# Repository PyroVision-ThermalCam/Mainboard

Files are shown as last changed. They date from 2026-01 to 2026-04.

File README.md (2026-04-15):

# PyroVision - Mainboard





## Table of Contents

- [PyroVision - Mainboard](#pyrovision---mainboard)
  - [Table of Contents](#table-of-contents)
  - [About](#about)
  - [License](#license)
  - [Maintainer](#maintainer)

## About

Mainboard for the PyroVision Open-Source Thermal Camera.

## License

This project is licensed under the GNU General Public License v3.0. See the [LICENSE](LICENSE) file for details.

## Maintainer

- [Daniel Kampert](mailto:daniel.kampert@kampis-elektroecke.de)

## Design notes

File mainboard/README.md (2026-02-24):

<p align="center" width="100%">
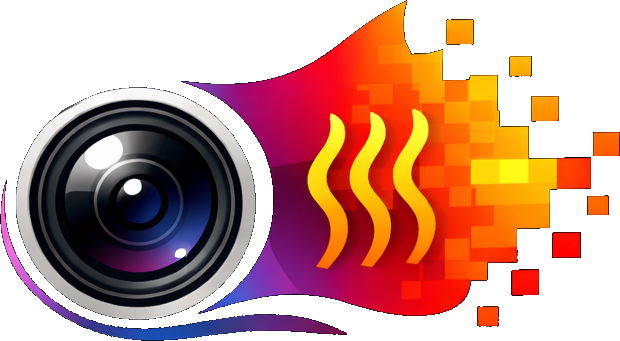
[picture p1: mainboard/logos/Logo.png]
  
</p>

<h1 align="center">PyroVision Mainboard</h1>

<p align="center" width="100%">
  <a href="${GIT_URL}/actions/workflows/pcb.yaml">
    CI Badge
  </a>
</p>

***

<p align="center">
  3D Top Angled
&nbsp; &nbsp; &nbsp; &nbsp;
  3D Bottom Angled
</p>

***

## SPECIFICATIONS

| Parameter | Value |
| --- | --- |
| Dimensions | 32.0 × 24.0 mm |

***

## DIRECTORY STRUCTURE

    .
    ├─ Computations       # Misc calculations
    ├─ HTML               # HTML files for generated webpage
    ├─ Images             # Pictures and renders
    │
    ├─ kibot_resources    # External resources for KiBot
    │  ├─ colors          # Color theme for KiCad
    │  ├─ fonts           # Fonts used in the project
    │  ├─ scripts         # External scripts used with KiBot
    │  └─ templates       # Templates for KiBot generated reports
    │
    ├─ kibot_yaml         # KiBot YAML config files
    ├─ KiRI               # KiRI (PCB diff viewer) files
    │
    ├─ lib                # KiCad footprint and symbol libraries
    │  ├─ 3d_models       # Component 3D models
    │  ├─ lib_fp          # Footprint libraries
    │  └─ lib_sym         # Symbol libraries
    │
    ├─ logos              # Logos
    │
    ├─ Manufacturing      # Assembly and fabrication documents
    │  ├─ Assembly        # Assembly documents (BoM, pos, notes)
    │  │
    │  └─ Fabrication     # Fabrication documents (ZIP, notes)
    │     ├─ Drill Tables # CSV drill tables
    │     └─ Gerbers      # Gerbers
    │
    ├─ Report             # Reports for ERC/DRC
    ├─ Schematic          # PDF of schematic
    ├─ templates          # Title block templates
    ├─ Testing
    │  └─ Testpoints      # Testpoints tables
    │
    └─ Variants           # Outputs for assembly variants

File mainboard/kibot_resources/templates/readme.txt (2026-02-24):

<p align="center" width="100%">
  
</p>

<h1 align="center">${BOARD_NAME}</h1>

<p align="center" width="100%">
  <a href="${GIT_URL}/actions/workflows/pcb.yml">
    CI Badge
  </a>
</p>

***

<p align="center">
  3D Top Angled
&nbsp; &nbsp; &nbsp; &nbsp;
  3D Bottom Angled
</p>

***

## SPECIFICATIONS

| Parameter | Value |
| --- | --- |
| Dimensions | ${bb_w_mm} × ${bb_h_mm} mm |

***

## DIRECTORY STRUCTURE

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

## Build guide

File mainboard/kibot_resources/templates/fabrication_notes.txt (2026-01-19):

FABRICATION NOTES (UNLESS OTHERWISE SPECIFIED)

1)	FABRICATE PER IPC-6012A CLASS 2.

2)	OUTLINE DEFINED IN SEPARATE GERBER FILE WITH
	"Edge_Cuts.GBR" SUFFIX.

	DIMENSIONS OF CIRCUMSIZED RECTANGLE SHOWN ON THIS
	DRAWING FOR REFERENCE ONLY.

3)	SEE SEPARATE DRILL FILES WITH ".DRL" SUFFIX 
	FOR HOLE LOCATIONS.

	SELECTED HOLE LOCATIONS SHOWN ON THIS DRAWING 
	FOR REFERENCE ONLY.

4)	SURFACE FINISH: ${pcb_finish_cap}

5)	SOLDERMASK ON BOTH SIDES OF THE BOARD SHALL 
	BE LPI, COLOR ${solder_mask_color_text_cap}.

6)	SILK SCREEN LEGEND TO BE APPLIED PER LAYER 
	STACKUP USING ${silk_screen_color_text_cap} NON-CONDUCTIVE EPOXY INK.

7)	ALL VIAS ARE TENTED ON BOTH SIDES UNLESS 
	SOLDERMASK OPENED IN GERBER.

8)	VENDOR SHOULD FOLLOW ROHS COMPLIANT PROCESS 
	AND Pb FREE FOR MANUFACTURING

9)	PCB MATERIAL REQUIREMENTS:

	A.	FLAMMABILITY RATING MUST MEET OR EXCEED 
		UL94V-0 REQUIREMENTS.
	B.	Tg 150 C OR EQUIVALENT.
	C.	EQUIVALENT MATERIAL SHALL BE RoHS COMPLIANT, 
		HALOGEN FREE AND APPROVED BY ${COMPANY_cap}.

10)	DESIGN GEOMETRY MINIMUM FEATURE SIZES:

	BOARD SIZE				${bb_w_mm} × ${bb_h_mm} mm
	BOARD THICKNESS		${thickness_mm} mm
	TRACE WIDTH			${track_mm} mm
	TRACE TO TRACE		${clearance_mm} mm
	MIN. HOLE (PTH)			${drill_pth_real_mm} mm
	MIN. HOLE (NPTH)		${drill_npth_real_mm} mm
	ANNULAR RING			${oar_mm} mm
	COPPER TO HOLE		${c2h_mm} mm
	COPPER TO EDGE		${c2e_mm} mm
	HOLE TO HOLE			${h2h_mm} mm
#?stackup and impedance_controlled

#?stackup and impedance_controlled
11)	REFER TO IMPEDANCE TABLE FOR IMPEDANCE CONTROL REQUIREMENTS.
#?stackup and impedance_controlled

#?stackup and impedance_controlled
12)	CONFIRM SPACE WIDTHS AND SPACINGS.

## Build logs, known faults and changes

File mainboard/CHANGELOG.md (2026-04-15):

# Changelog

## [Unreleased]

## [1.0.3] - 2026-04-15

**Added:**

- Add optional GND connection for camera AF on pin 24

**Removed:**

- Remove camera PWD signal from camera power supply enable

## [1.0.2](https://github.com/PyroVision-ThermalCam/Mainboard/compare/1.0.1...1.0.2) - 2026-02-24

**Fixed:**

- Add missing name for net for TP701 (#11)
- Wrong part number for IC804 (#17)
- Wrong part number for DFE201610E - R47M (#16)
- IC806 is set to DNP (#14)
- Remove camera PWD signal from camera power supply enable

**Added:**

- Connect the TMP117 temperature alert pin (#21)
- Add missing GND connection for camera AF on pin 24

**Changed:**

- Replace PGDWT-BS-0000-00Q2E with XPGDWT-BS-0000-00P5E (#18)
- Replace JS1400BFQ with MU-BUE70R (#19)
- Replace SD card holder with MSD-4-A (#10)
- Replace TS11-674-50-BK-260-RA-D with TS11-674-43-BK-260-RA-D (#12)
- Replace TXB0102DCUT with TXB0102DCUR (#15)

## [1.0.1](https://github.com/PyroVision-ThermalCam/Mainboard/compare/67de4a6eec24cc332c0ba283ca204f24177bcb72...1.0.1) - 2026-01-21

**Changed:**

- Increase the width of the cutout for the temperature sensor (#7)

## [1.0.0](https://github.com/PyroVision-ThermalCam/Mainboard/compare/67de4a6eec24cc332c0ba283ca204f24177bcb72...1.0.0) - 2026-01-19

**Added:**

- Initial release

[unreleased]: https://github.com/PyroVision-ThermalCam/Mainboard/compare/1.0.3...HEAD
[1.0.3]: https://github.com/PyroVision-ThermalCam/Mainboard/compare/67de4a6eec24cc332c0ba283ca204f24177bcb72...1.0.3

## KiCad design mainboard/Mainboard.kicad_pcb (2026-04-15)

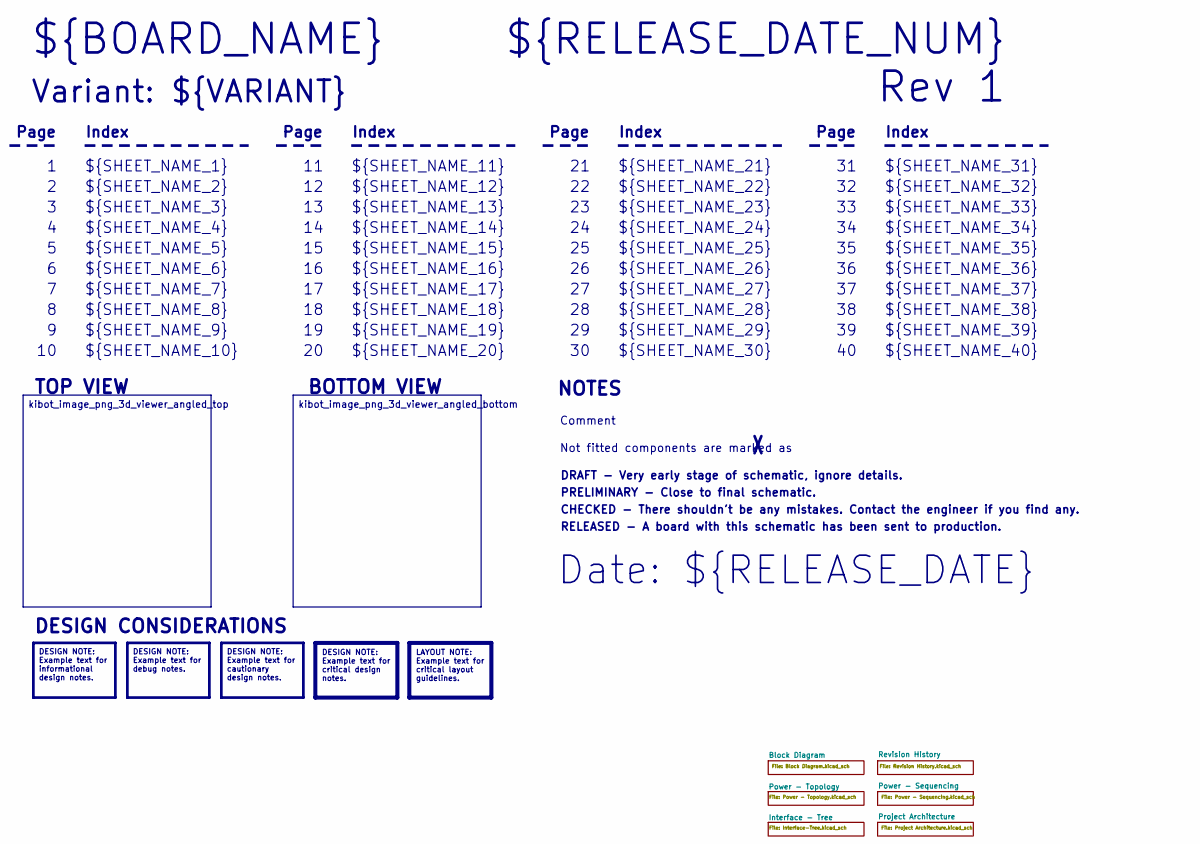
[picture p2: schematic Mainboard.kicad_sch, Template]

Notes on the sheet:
Variant: ${VARIANT}
RELEASED - A board with this schematic has been sent to production.
${SHEET_NAME_24}
Index
Page
PRELIMINARY - Close to final schematic.
${SHEET_NAME_22}
DRAFT - Very early stage of schematic, ignore details.
${SHEET_NAME_12}
${SHEET_NAME_8}
${SHEET_NAME_2}
${SHEET_NAME_5}
${SHEET_NAME_20}
${SHEET_NAME_23}
${RELEASE_DATE_NUM}
${SHEET_NAME_35}
Not fitted components are marked as
${SHEET_NAME_11}
${SHEET_NAME_6}
${SHEET_NAME_37}
${SHEET_NAME_26}
${SHEET_NAME_36}
Rev ${REVISION}
${SHEET_NAME_15}
CHECKED - There shouldn't be any mistakes. Contact the engineer if you find any.
BOTTOM VIEW
${SHEET_NAME_14}
${SHEET_NAME_21}
${SHEET_NAME_17}
${SHEET_NAME_18}
Date: ${RELEASE_DATE}
${SHEET_NAME_7}
${SHEET_NAME_31}
${BOARD_NAME}
NOTES
${SHEET_NAME_40}
${SHEET_NAME_39}
${SHEET_NAME_32}
${SHEET_NAME_1}
${SHEET_NAME_9}

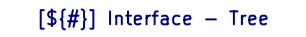
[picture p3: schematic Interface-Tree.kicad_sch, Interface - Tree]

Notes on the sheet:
[${#}] ${TITLE}

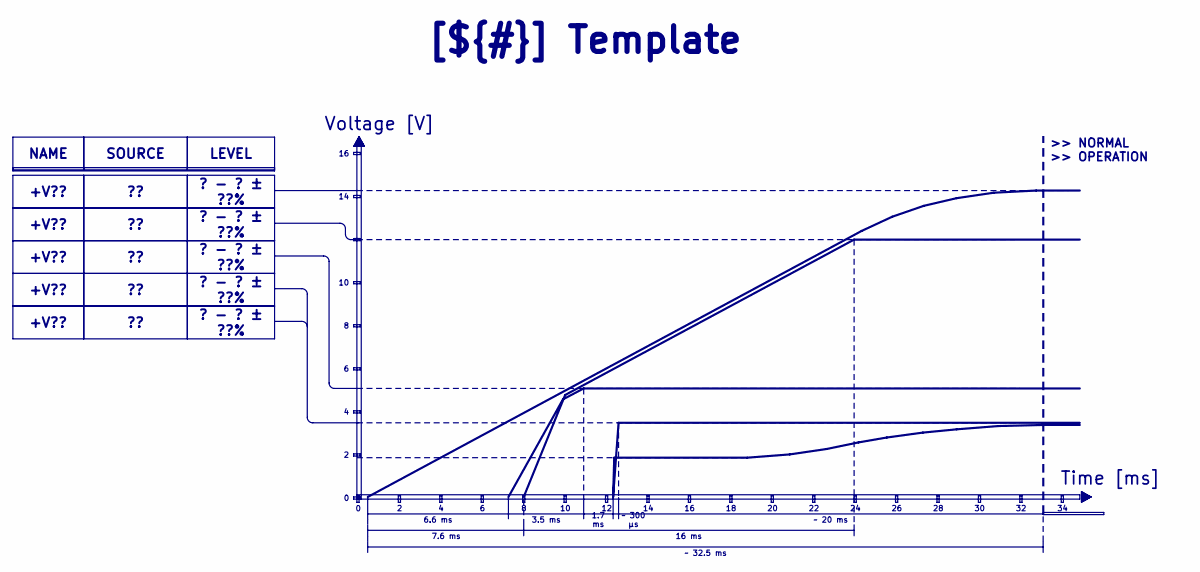
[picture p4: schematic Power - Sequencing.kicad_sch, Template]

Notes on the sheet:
Voltage [V]
>> NORMAL >> OPERATION
Time [ms]
3.5 ms
7.6 ms
? - ? ± ??%
~ 300 μs
1.7 ms
16 ms
+V??
LEVEL
NAME
~ 20 ms
SOURCE
[${#}] ${TITLE}
6.6 ms
~ 32.5 ms

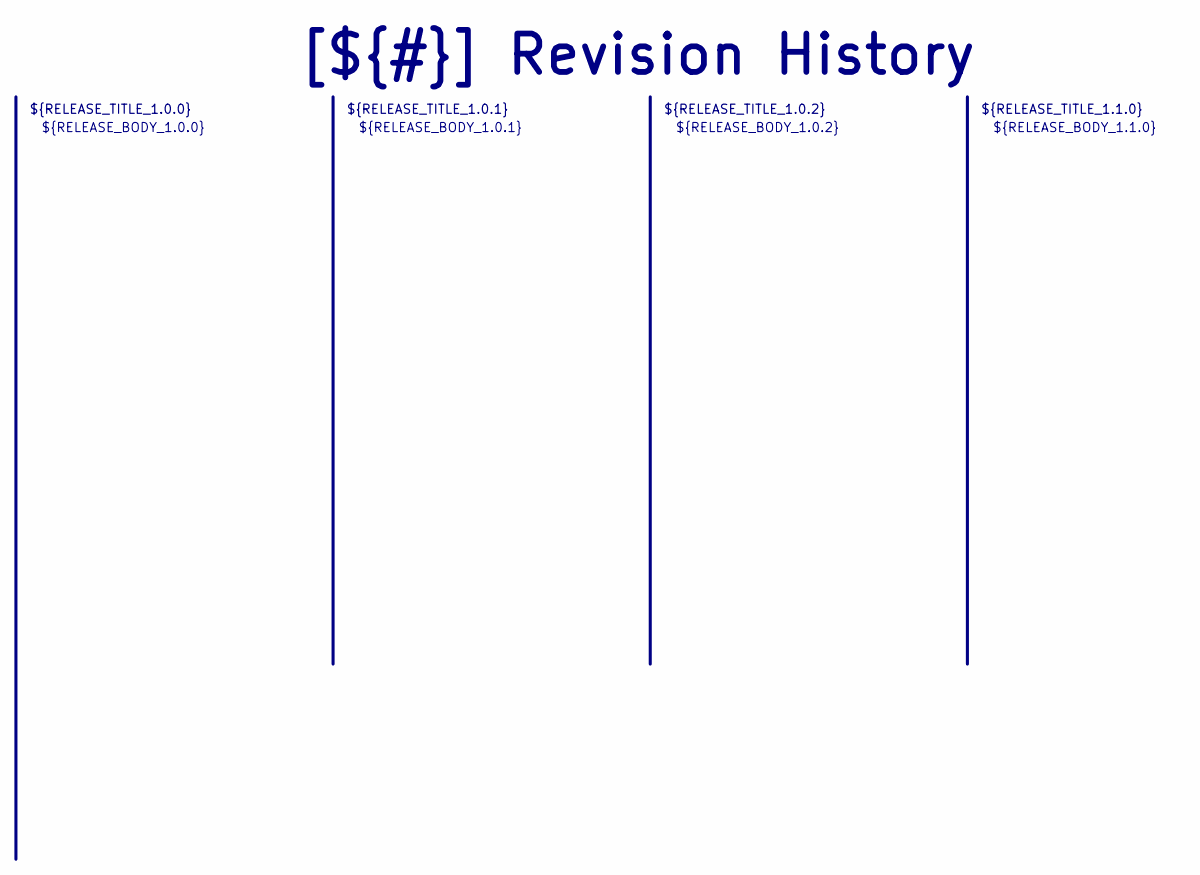
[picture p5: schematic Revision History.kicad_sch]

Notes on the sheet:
${RELEASE_BODY_1.1.0}
${RELEASE_BODY_1.0.0}
[${#}] ${TITLE}
${RELEASE_TITLE_1.0.2}
${RELEASE_BODY_1.0.2}
${RELEASE_BODY_1.0.1}
${RELEASE_TITLE_1.0.0}
${RELEASE_TITLE_1.0.1}
${RELEASE_TITLE_1.1.0}

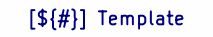
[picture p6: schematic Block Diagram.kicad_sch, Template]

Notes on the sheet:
[${#}] ${TITLE}

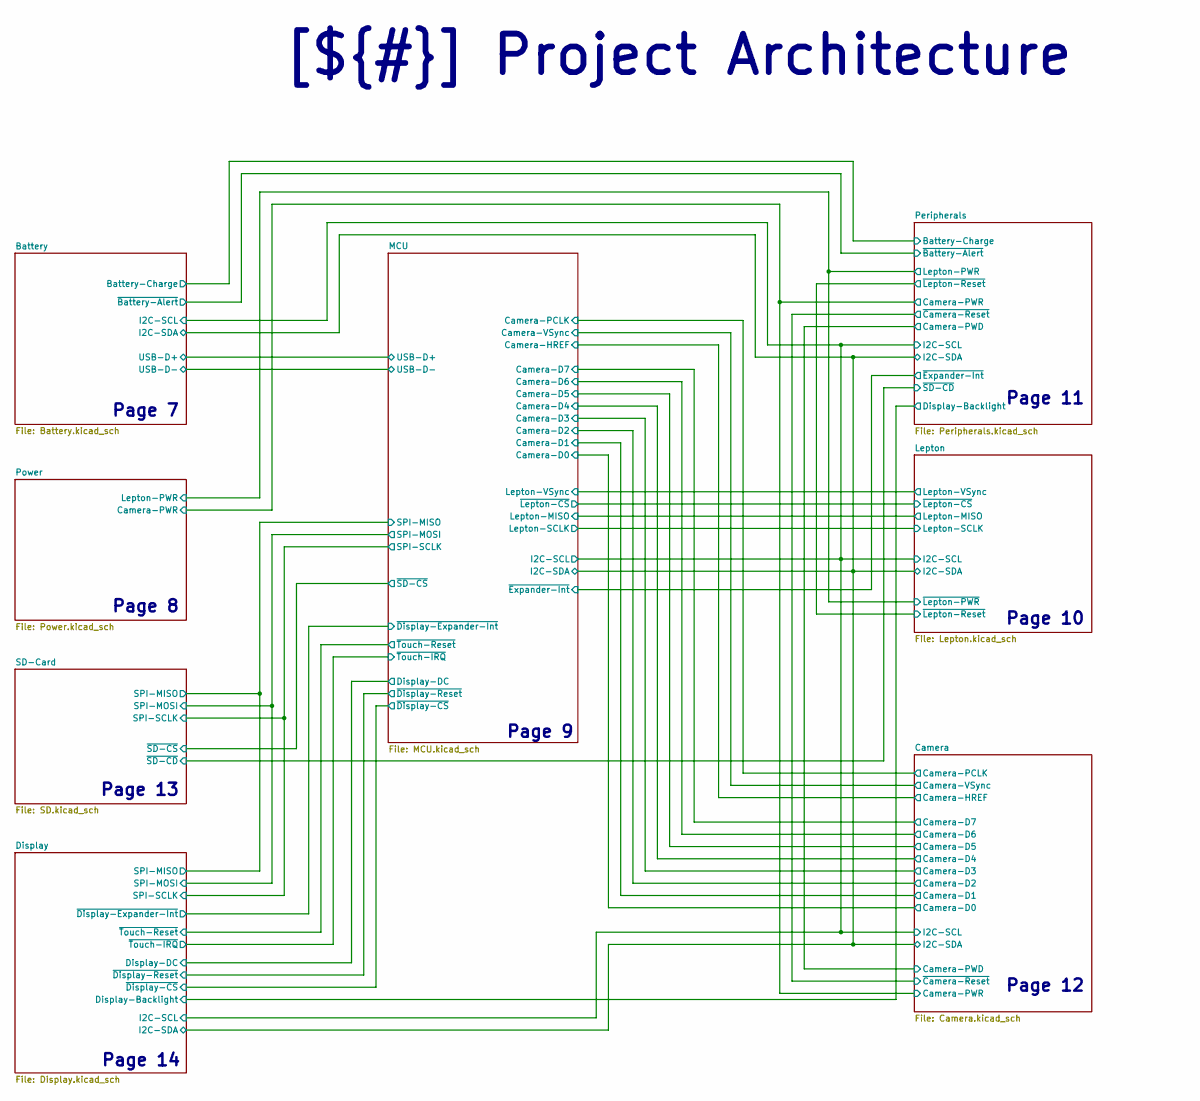
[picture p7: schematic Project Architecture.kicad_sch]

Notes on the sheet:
Page 12
Page 11
Page 13
Page 8
Page 10
Page 7
Page 14
Page 9
[${#}] ${TITLE}

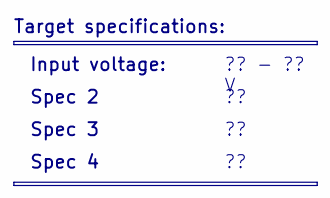
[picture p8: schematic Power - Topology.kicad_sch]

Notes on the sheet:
Spec 2
Input voltage:
Spec 4
?? - ?? V
Target specifications:
Spec 3

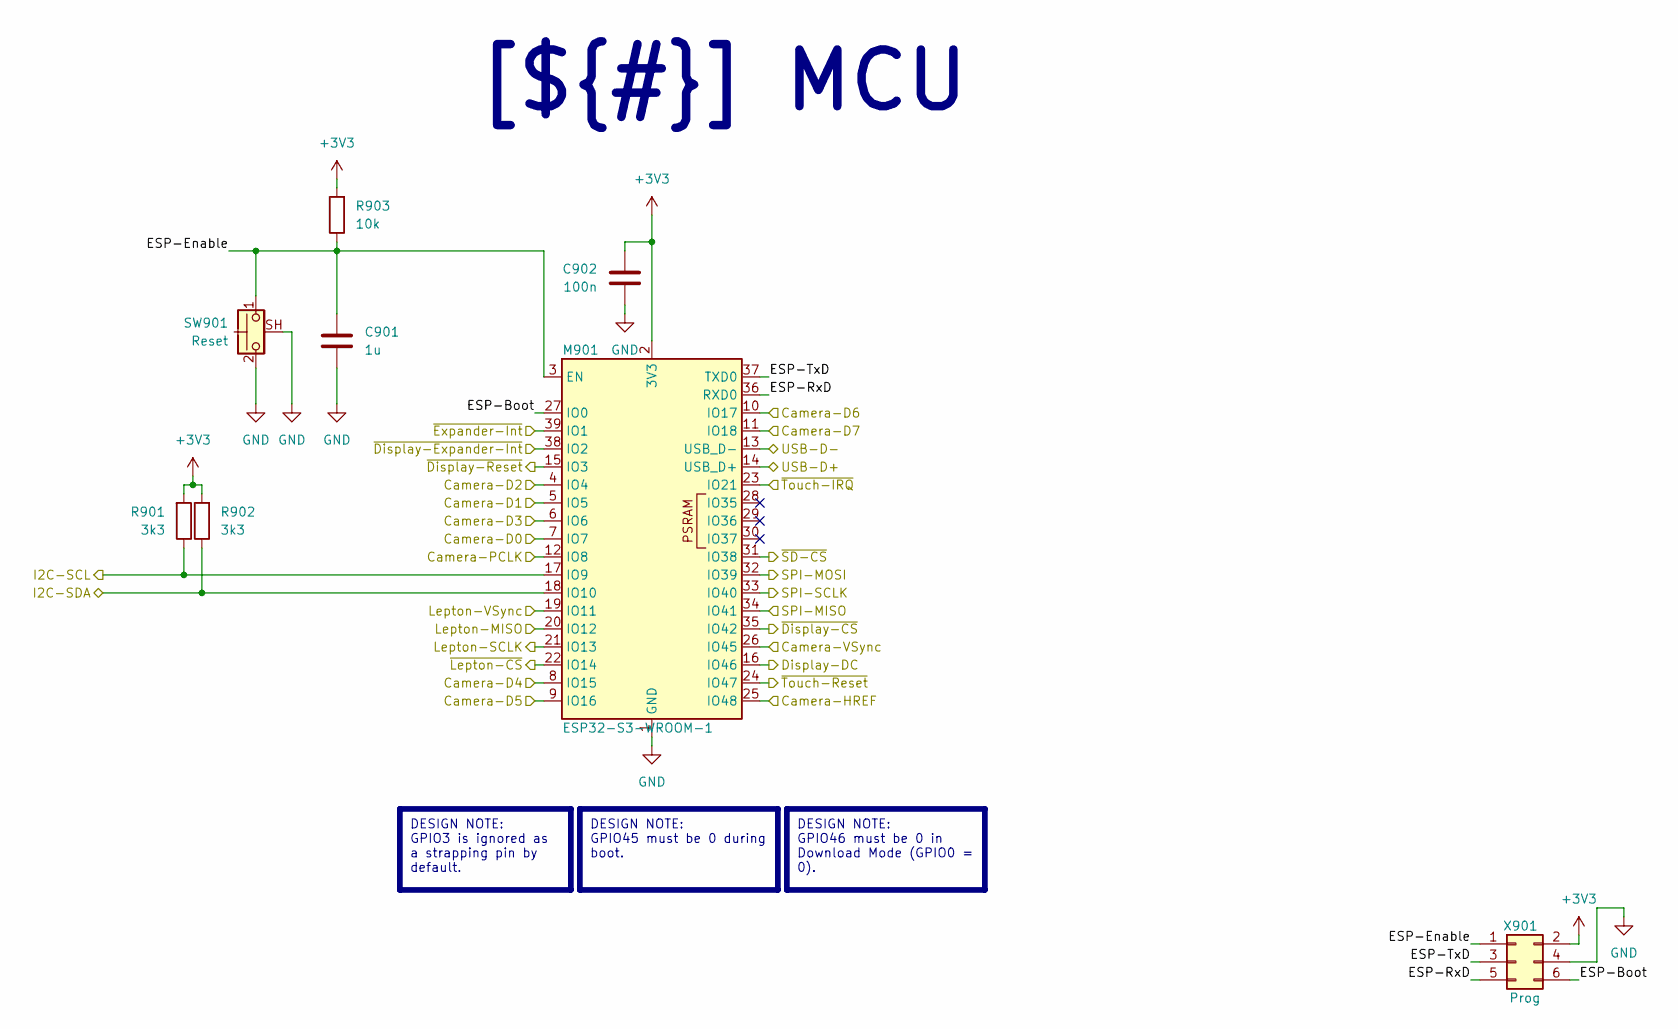
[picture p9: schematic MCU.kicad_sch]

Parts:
C901: 1u; C_0603_1608Metric; mouser# 581-06036C105MAT2A
C902: 100n; C_0603_1608Metric; mouser# 581-06031C104MAT2A
M901: ESP32-S3-WROOM-1; mouser# 356-ESP32-S3-WROOM-2-N32R16V
R901, R902: 3k3; R_0603_1608Metric; mouser# 603-RC0603FR-073K3L
R903: 10k; R_0603_1608Metric; mouser# 603-RC0603FR-073K3L
SW901: Reset; TS11; mouser# 179-TS1167443260RAD
X901: Prog; 490107670612-Debugging

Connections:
+3V3: C902.1, M901.2 (3V3), R901.2, R902.2, R903.2, X901.2; also elsewhere on the board
/Project Architecture/Battery/I2C-SCL: M901.17 (IO9), R901.1; also elsewhere on the board
/Project Architecture/Battery/I2C-SDA: M901.18 (IO10), R902.1; also elsewhere on the board
/Project Architecture/Battery/USB-D+: M901.14 (USB_D+); also elsewhere on the board
/Project Architecture/Battery/USB-D-: M901.13 (USB_D-); also elsewhere on the board
/Project Architecture/Camera/Camera-D0: M901.7 (IO7); also elsewhere on the board
/Project Architecture/Camera/Camera-D1: M901.5 (IO5); also elsewhere on the board
/Project Architecture/Camera/Camera-D2: M901.4 (IO4); also elsewhere on the board
/Project Architecture/Camera/Camera-D3: M901.6 (IO6); also elsewhere on the board
/Project Architecture/Camera/Camera-D4: M901.8 (IO15); also elsewhere on the board
/Project Architecture/Camera/Camera-D5: M901.9 (IO16); also elsewhere on the board
/Project Architecture/Camera/Camera-D6: M901.10 (IO17); also elsewhere on the board
/Project Architecture/Camera/Camera-D7: M901.11 (IO18); also elsewhere on the board
/Project Architecture/Camera/Camera-HREF: M901.25 (IO48); also elsewhere on the board
/Project Architecture/Camera/Camera-PCLK: M901.12 (IO8); also elsewhere on the board
/Project Architecture/Camera/Camera-VSync: M901.26 (IO45); also elsewhere on the board
/Project Architecture/Display/Display-DC: M901.16 (IO46); also elsewhere on the board
/Project Architecture/Display/SPI-MISO: M901.34 (IO41); also elsewhere on the board
/Project Architecture/Display/SPI-MOSI: M901.32 (IO39); also elsewhere on the board
/Project Architecture/Display/SPI-SCLK: M901.33 (IO40); also elsewhere on the board
/Project Architecture/Display/~Display-CS: M901.35 (IO42); also elsewhere on the board
/Project Architecture/Display/~Display-Expander-Int: M901.38 (IO2); also elsewhere on the board
/Project Architecture/Display/~Display-Reset: M901.15 (IO3); also elsewhere on the board
/Project Architecture/Display/~Touch-IRQ: M901.23 (IO21); also elsewhere on the board
/Project Architecture/Display/~Touch-Reset: M901.24 (IO47); also elsewhere on the board
/Project Architecture/Lepton/Lepton-MISO: M901.20 (IO12); also elsewhere on the board
/Project Architecture/Lepton/Lepton-SCLK: M901.21 (IO13); also elsewhere on the board
/Project Architecture/Lepton/Lepton-VSync: M901.19 (IO11); also elsewhere on the board
/Project Architecture/Lepton/~Lepton-CS: M901.22 (IO14); also elsewhere on the board
/Project Architecture/MCU/ESP-Boot: M901.27 (IO0), X901.6
/Project Architecture/MCU/ESP-Enable: C901.1, M901.3 (EN), R903.1, SW901.1, X901.1
/Project Architecture/MCU/ESP-RxD: M901.36 (RXD0), X901.5
/Project Architecture/MCU/ESP-TxD: M901.37 (TXD0), X901.3
/Project Architecture/MCU/~Expander-Int: M901.39 (IO1); also elsewhere on the board
/Project Architecture/MCU/~SD-CS: M901.31 (IO38); also elsewhere on the board
GND: C901.2, C902.2, M901.1 (GND), M901.40 (GND), M901.41 (GND), SW901.2, SW901.SH (B), X901.4; also elsewhere on the board

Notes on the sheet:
DESIGN NOTE: GPIO45 must be 0 during boot.
DESIGN NOTE: GPIO46 must be 0 in Download Mode (GPIO0 = 0).
DESIGN NOTE: GPIO3 is ignored as a strapping pin by default.
[${#}] ${TITLE}

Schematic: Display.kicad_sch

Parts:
R1401, R1402, R1403, R1404, R1405: 100k; R_0603_1608Metric; mouser# 652-CR0603-JW-104ELF
X1401: Displayboard; Amphenol_F32R-1A7x1-11014_1x14-1MP_P0.5mm_Horizontal; mouser# 649-F32R-1A7H1-11014

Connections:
+3V3: R1401.2, R1402.2, R1403.2, R1404.2, R1405.2, X1401.14; also elsewhere on the board
/Project Architecture/Battery/I2C-SCL: X1401.9; also elsewhere on the board
/Project Architecture/Battery/I2C-SDA: X1401.10; also elsewhere on the board
/Project Architecture/Display/Display-Backlight: X1401.1; also elsewhere on the board
/Project Architecture/Display/Display-DC: X1401.5; also elsewhere on the board
/Project Architecture/Display/SPI-MISO: X1401.2; also elsewhere on the board
/Project Architecture/Display/SPI-MOSI: X1401.3; also elsewhere on the board
/Project Architecture/Display/SPI-SCLK: X1401.6; also elsewhere on the board
/Project Architecture/Display/~Display-CS: R1401.1, X1401.4; also elsewhere on the board
/Project Architecture/Display/~Display-Expander-Int: R1404.1, X1401.8; also elsewhere on the board
/Project Architecture/Display/~Display-Reset: R1405.1, X1401.7; also elsewhere on the board
/Project Architecture/Display/~Touch-IRQ: R1403.1, X1401.11; also elsewhere on the board
/Project Architecture/Display/~Touch-Reset: R1402.1, X1401.12; also elsewhere on the board
GND: X1401.13, X1401.MP (MountPin); also elsewhere on the board

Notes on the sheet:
6. SPI-SCLK
10. SDA
12. ~{Touch-Reset}
7. ~{Display-Reset}
13. GND
1. Display-Backlight
4. ~{Display-CS}
5. Display-DC
11. ~{Touch-IRQ}
3. SPI-MOSI
8. ~{Display-Expander-Int}
14. +3V3
2. SPI-MISO
9. SCL
[${#}] ${TITLE}

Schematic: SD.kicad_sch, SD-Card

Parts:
C1301: 100n; C_0603_1608Metric; mouser# 581-06031C104MAT2A
R1301: 100k; R_0603_1608Metric; mouser# 652-CR0603-JW-104ELF; not fitted
X1301: Micro SD-Card; MSD-4-A; mouser# 179-MSD-4-A

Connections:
+3V3: R1301.2, X1301.4 (VDD); also elsewhere on the board
/Project Architecture/Display/SPI-MISO: X1301.7 (DAT0); also elsewhere on the board
/Project Architecture/Display/SPI-MOSI: X1301.3 (CMD); also elsewhere on the board
/Project Architecture/Display/SPI-SCLK: X1301.5 (CLK); also elsewhere on the board
/Project Architecture/MCU/~SD-CS: X1301.2 (DAT3/CD); also elsewhere on the board
/Project Architecture/Peripherals/~SD-CD: C1301.1, R1301.1, X1301.9 (DET); also elsewhere on the board
GND: C1301.2, X1301.6 (VSS), X1301.10 (SHIELD); also elsewhere on the board

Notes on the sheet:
[${#}] ${TITLE}

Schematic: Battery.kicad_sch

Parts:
C701, C702: 1u; C_0603_1608Metric; mouser# 581-06036C105MAT2A
C703: 100n; C_0603_1608Metric; mouser# 581-06031C104MAT2A
F701: 6 V / 4.5 A; Fuse_1206_3216Metric; mouser# 576-1206L450SLWR
IC701: USBLC6-2P6; SOT-666; mouser# 511-USBLC6-2P6
IC702: BQ21040DBV; SOT-23-6; mouser# 595-BQ21040DBVR
IC703: MAX17048; TDFN-8-1EP_2x2mm_P0.5mm_EP0.8x1.2mm; mouser# 700-MAX17048G+T10
Q701: Si2333CDS; SOT-23-3; mouser# 78-SI2333CDS-T1-BE3
R701, R702: 5k1; R_0603_1608Metric; mouser# 652-CR0603-JW-512ELF
R703, R709: 1k; R_0603_1608Metric; mouser# 652-CR0603-JW-102ELF
R704, R710: 100k; R_0603_1608Metric; mouser# 652-CR0603-JW-104ELF; not fitted
R705, R708: 0R; R_1206_3216Metric; mouser# 652-CR1206-J/-000ELF; not fitted
R706, R707, R711: 0R; R_1206_3216Metric; mouser# 652-CR1206-J/-000ELF
TH701: 10k; R_0603_1608Metric; mouser# 603-RC0603FR-073K3L
TP701, TP702, TP703: TestPoint_Pad_1.0x1.0mm
X701: USB; USB_C_Receptacle_GCT_USB4110; mouser# 640-USB4110-GF-A
X702: Battery; S2B-PH-SM4-TB; mouser# 306-S2B-PH-SM4-TB(LF)(SN)

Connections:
+3V3: R704.2, R710.2; also elsewhere on the board
+BATT: R711.2, TP703.1; also elsewhere on the board
/Project Architecture/Battery/Battery-Charge: IC702.3 (~CHG), R704.1; also elsewhere on the board
/Project Architecture/Battery/I2C-SCL: IC703.7 (SCL); also elsewhere on the board
/Project Architecture/Battery/I2C-SDA: IC703.8 (SDA); also elsewhere on the board
/Project Architecture/Battery/USB-D+: IC701.4 (I/O2); also elsewhere on the board
/Project Architecture/Battery/USB-D-: IC701.6 (I/O1); also elsewhere on the board
/Project Architecture/Battery/VBat: C702.1, F701.1, IC702.2 (OUT), R705.2, R707.2, TP701.1
/Project Architecture/Battery/~Battery-Alert: IC703.5 (~ALERT), R710.1, TP702.1; also elsewhere on the board
GND: C701.2, C702.2, C703.2, IC701.2 (GND), IC702.5 (GND), IC703.1 (CTG), IC703.4 (GND), IC703.6 (QSTRT), IC703.9 (EP), R701.1, R702.1, R703.1, R706.1, R708.2, R709.1, TH701.2, X701.A1 (GND), X701.A12 (GND), X701.B1 (GND), X701.B12 (GND), X701.S1 (SHIELD); also elsewhere on the board
unnamed: IC701.1 (I/O1), X701.A7 (D-), X701.B7 (D-)
unnamed: IC701.3 (I/O2), X701.A6 (D+), X701.B6 (D+)
unnamed: C701.1, IC701.5 (VBUS), IC702.6 (VIN), X701.A4 (VBUS), X701.A9 (VBUS), X701.B4 (VBUS), X701.B9 (VBUS)
unnamed: IC702.4 (ISET), R703.2
unnamed: IC702.1 (TS), TH701.1
unnamed: C703.1, IC703.2 (CELL), IC703.3 (VDD), Q701.2 (S), R711.1
unnamed: F701.2, Q701.3 (D)
unnamed: Q701.1 (G), R709.2
unnamed: R702.2, X701.A5 (CC1)
unnamed: R701.2, X701.B5 (CC2)
unnamed: R705.1, R706.2, X702.1
unnamed: R707.1, R708.1, X702.2

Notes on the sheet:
[${#}] ${TITLE}
LAYOUT NOTE: 90 Ohms ± 15%
DESIGN NOTE: Can be replaced with static 10k, if not needed.
DESIGN NOTE: Calculated for a charging current of 540 mA.
Battery connector
DESIGN NOTE: These resistors can be used to swap the polarity of the battery connector.
Reverse and overcurrent protection
LiPo Charger
LiPo Gauge

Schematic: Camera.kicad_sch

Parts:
C1201: 10n; C_0603_1608Metric; mouser# 581-06035A103KAT2A
IC1201: TXB0102DCU; VSSOP-8_2.3x2mm_P0.5mm; mouser# 595-TXB0102DCUR
IC1202: PCA9306JK; XSON-8_0.65x0.17mm_P0.35mm; mouser# 771-PCA9306JKZ
R1201: 0R; R_0603_1608Metric; mouser# 652-CR1206-J/-000ELF
R1202, R1203: 100k; R_0603_1608Metric; mouser# 652-CR0603-JW-104ELF
R1204, R1205: 2k8; R_0603_1608Metric; mouser# 603-RC0603FR-072K8L
R1206: 200k; R_0603_1608Metric; mouser# 603-RC0603FR-07200KL
X1201: Camera; Amphenol_F32R-1A7x1-11024_1x24-1MP_P0.5mm_Horizontal; mouser# 649-F32R-1A7H1-11024
Y1201: 25 MHz; Oscillator_SMD_Abracon_ASDMB-4Pin_2.5x2.0mm; mouser# 815-ASDDV2500MHZLCT3

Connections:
+3V3: IC1201.3 (VCCA), IC1201.6 (OE), R1201.2, R1203.2, R1206.1; also elsewhere on the board
/Project Architecture/Battery/I2C-SCL: IC1202.6 (SCL_{2}); also elsewhere on the board
/Project Architecture/Battery/I2C-SDA: IC1202.5 (SDA_{2}); also elsewhere on the board
/Project Architecture/Camera/Camera-D0: X1201.6; also elsewhere on the board
/Project Architecture/Camera/Camera-D1: X1201.4; also elsewhere on the board
/Project Architecture/Camera/Camera-D2: X1201.3; also elsewhere on the board
/Project Architecture/Camera/Camera-D3: X1201.5; also elsewhere on the board
/Project Architecture/Camera/Camera-D4: X1201.7; also elsewhere on the board
/Project Architecture/Camera/Camera-D5: X1201.9; also elsewhere on the board
/Project Architecture/Camera/Camera-D6: X1201.11; also elsewhere on the board
/Project Architecture/Camera/Camera-D7: X1201.13; also elsewhere on the board
/Project Architecture/Camera/Camera-HREF: X1201.16; also elsewhere on the board
/Project Architecture/Camera/Camera-PCLK: X1201.8; also elsewhere on the board
/Project Architecture/Camera/Camera-PWD: IC1201.4 (A2), R1203.1; also elsewhere on the board
/Project Architecture/Camera/Camera-PWD_{LV}: IC1201.1 (B2), X1201.17
/Project Architecture/Camera/Camera-VSync: X1201.18; also elsewhere on the board
/Project Architecture/Camera/MCLK: X1201.12, Y1201.3 (OUT)
/Project Architecture/Camera/SCL_{LV}: IC1202.3 (SCL_{1}), R1204.1, X1201.20
/Project Architecture/Camera/SDA_{LV}: IC1202.4 (SDA_{1}), R1205.1, X1201.22
/Project Architecture/Camera/~Camera-Reset: IC1201.5 (A1), R1202.2; also elsewhere on the board
/Project Architecture/Camera/~Camera-Reset_{LV}: IC1201.8 (B1), X1201.19
Camera-1V5: X1201.15; also elsewhere on the board
Camera-2V8: C1201.1, IC1201.7 (VCCB), IC1202.2 (VCC_{1}), R1204.2, R1205.2, X1201.14, X1201.21, Y1201.1 (Tri-State), Y1201.4 (VDD); also elsewhere on the board
GND: C1201.2, IC1201.2 (GND), IC1202.1 (GND), R1202.1, X1201.1, X1201.10, X1201.23, X1201.MP (MountPin), Y1201.2 (GND); also elsewhere on the board
unnamed: IC1202.7 (VCC_{2}), IC1202.8 (EN), R1206.2
unnamed: R1201.1, X1201.2

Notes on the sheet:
14. DOVDD
16. HREF
17. PWDN
21. AVDD
15. DVDD
5. Y5
9. Y7
10. DGND
2. Y1
11. Y8
4. Y3
1. Y0
22 SIO_D
19. RST
12. XCLK
6. Y2
24. NC
20. SIO_C
3. Y4
8. PCLK
18. VSYNC
7. Y6
13. Y9
23. AGND
DESIGN NOTE: The camera use an internal pull-down.
OV5640 camera connector
DESIGN NOTE: The camera use an internal pull-up.
[${#}] ${TITLE}
Level shifting (Camera IO <> System Voltage)
DESIGN NOTE: This pin is used for the AF power supply.

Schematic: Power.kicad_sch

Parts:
C801: 4u7; C_0603_1608Metric; mouser# 581-06036D475MAT4A
C802, C803, C804, C805, C807, C808, C809, C810, C811, C812: 1u; C_0603_1608Metric; mouser# 581-06036C105MAT2A
C806: 10u; C_0603_1608Metric; mouser# 581-06034D106K
IC801, IC805: LP5907MFX-2.8; SOT-23-5; mouser# 595-LP5907MFX-2.8/NOPB
IC802: LP5907MFX-1.5; SOT-23-5; mouser# 595-LP5907MFX-1.5/NOPB
IC803: TPS62823DLC; Texas_VSON-HR-8_1.5x2mm_P0.5mm; mouser# 595-TPS62823DLCR
IC804: LP5907MFX-3.0; SOT-23-5; mouser# 595-LP5907MFX-3.0NPB
IC806: LP5907MFX-1.2; SOT-23-5; mouser# 595-LP5907MFX-1.2/NOPB
L801: 470n; L_Murata_DFE201610P; mouser# 81-DFE201610E-R47MP2
R801: 100k; R_0603_1608Metric; mouser# 652-CR0603-JW-104ELF
R802, R803, R806, R807, R808: 100k; R_0603_1608Metric; mouser# 652-CR0603-JW-104ELF; not fitted
R804: 45k3; R_0603_1608Metric; mouser# 652-CR0603-FX-4532ELF
R805: 10k; R_0603_1608Metric; mouser# 603-RC0603FR-0710KL
SW801: On / Off; SW_Slide_SPDT_Angled_CK_OS102011MA1Q; mouser# 611-OS102011MA1QN1
TP801, TP802, TP803, TP804, TP805, TP806: TestPoint_Pad_1.0x1.0mm

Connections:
+3V3: C802.1, C803.1, C806.1, C807.1, C808.1, C809.1, IC801.1 (IN), IC802.1 (IN), IC804.1 (IN), IC805.1 (IN), IC806.1 (IN), L801.2, R804.1, TP803.1; also elsewhere on the board
+BATT: C801.1, IC803.7 (VIN), SW801.3 (C); also elsewhere on the board
/Project Architecture/Lepton/~Lepton-PWR: IC804.3 (EN), IC805.3 (EN), IC806.3 (EN), R806.1, R807.1, R808.1; also elsewhere on the board
/Project Architecture/Peripherals/Camera-PWR: IC801.3 (EN), IC802.3 (EN), R802.1, R803.1; also elsewhere on the board
Camera-1V5: C805.1, IC802.5 (OUT), TP802.1; also elsewhere on the board
Camera-2V8: C804.1, IC801.5 (OUT), TP801.1; also elsewhere on the board
GND: C801.2, C802.2, C803.2, C804.2, C805.2, C806.2, C807.2, C808.2, C809.2, C810.2, C811.2, C812.2, IC801.2 (GND), IC802.2 (GND), IC803.3 (AGND), IC803.5 (PGND), IC804.2 (GND), IC805.2 (GND), IC806.2 (GND), R801.2, R802.2, R803.2, R805.2, R806.2, R807.2, R808.2; also elsewhere on the board
Lepton-1V2: C812.1, IC806.5 (OUT), TP806.1; also elsewhere on the board
Lepton-2V8: C811.1, IC805.5 (OUT), TP805.1; also elsewhere on the board
Lepton-3V0: C810.1, IC804.5 (OUT), TP804.1; also elsewhere on the board
unnamed: IC803.1 (EN), SW801.2 (B)
unnamed: IC803.2 (FB), R804.2, R805.1
unnamed: IC803.6 (SW), L801.1
unnamed: R801.1, SW801.1 (A)

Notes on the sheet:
VDDC (0.3 W)
VDDA (0.7 W)
VDDIO (1.5 W)
+3V3 (9.9 W)
VDD (0.7 W)
VDDC (0.375 W)
Main Power
Lepton Power
DESIGN NOTE: I_{DDIO} is specified with up to 310 mA.
Camera Power
[${#}] ${TITLE}

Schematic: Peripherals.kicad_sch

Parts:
C1101, C1102, C1103, C1104, C1105, C1106: 100n; C_0603_1608Metric; mouser# 581-06031C104MAT2A
C1107: 4u7; C_0603_1608Metric; mouser# 581-06036D475MAT4A
D1101, D1102: Flash; XP-G; mouser# 941-XPGDWT-BS-0000-00P5E
IC1101: PCAL6416AHF; HVQFN-24-1EP_4x4mm_P0.5mm_EP2.1x2.1mm; mouser# 771-PCAL6416AHF,128
IC1102: TMP117xxYBG; WSON-6-1EP_2x2mm_P0.65mm_EP1x1.6mm; mouser# 595-TMP117MAIDRVR
IC1103: PCA9306JK; XSON-8_0.65x0.17mm_P0.35mm; mouser# 771-PCA9306JKZ
IC1104: PCA9633DP1,118; TSSOP-8_3x3mm_P0.65mm; mouser# 771-PCA9633DP1,118
IC1105: RV-8263-C8; mouser# 428-204291-MC01
IC1106: VL53L1CXV0FY1; ST_VL53L1x; mouser# 511-VL53L1CXV0FY/1
Q1101, Q1102: DMN2053UQ; SOT-23; mouser# 621-DMN2053UQ-7
R1101, R1102, R1103, R1106, R1115: 100k; R_0603_1608Metric; mouser# 652-CR0603-JW-104ELF
R1104, R1107: 10R; R_1206_3216Metric; mouser# 71-RCA120610R0FKEASR
R1105, R1108, R1109, R1113, R1114: 3k3; R_0603_1608Metric; mouser# 603-RC0603FR-073K3L; not fitted
R1110: 200k; R_0603_1608Metric; mouser# 603-RC0603FR-07200KL
R1111, R1112: 3k3; R_0603_1608Metric; mouser# 603-RC0603FR-073K3L
TP1101, TP1102, TP1103, TP1104, TP1105, TP1106, TP1107, TP1108, TP1109, TP1110, TP1111, TP1112, TP1113: TestPoint_Pad_1.0x1.0mm

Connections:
+3V3: C1102.1, C1103.1, C1104.1, C1106.1, C1107.1, IC1101.21 (V_{DD(P)}), IC1101.23 (V_{DD(I2C-bus)}), IC1102.5 (V+), IC1103.2 (VCC_{1}), IC1104.8 (VDD), IC1106.1 (AVDDVCSEL), IC1106.11 (AVDD), R1101.2, R1102.2, R1105.2, R1108.2, R1109.2, R1113.2, R1114.2, R1115.1; also elsewhere on the board
+BATT: C1105.1, IC1105.5 (V_{DD}), R1104.2, R1107.2, R1110.1, R1111.2, R1112.2; also elsewhere on the board
/Project Architecture/Battery/Battery-Charge: IC1101.2 (P0_1), TP1109.1; also elsewhere on the board
/Project Architecture/Battery/I2C-SCL: IC1101.19 (SCL), IC1102.1 (SCL), IC1103.3 (SCL_{1}), IC1104.6 (SCL), IC1106.10 (SCL), R1108.1, TP1102.1; also elsewhere on the board
/Project Architecture/Battery/I2C-SDA: IC1101.20 (SDA), IC1102.6 (SDA), IC1103.4 (SDA_{1}), IC1104.7 (SDA), IC1106.9 (SDA), R1109.1, TP1101.1; also elsewhere on the board
/Project Architecture/Battery/~Battery-Alert: IC1101.1 (P0_0); also elsewhere on the board
/Project Architecture/Camera/Camera-PWD: IC1101.13 (P1_3); also elsewhere on the board
/Project Architecture/Camera/~Camera-Reset: IC1101.16 (P1_6), TP1104.1; also elsewhere on the board
/Project Architecture/Display/Display-Backlight: IC1104.3 (LED2); also elsewhere on the board
/Project Architecture/Lepton/~Lepton-PWR: IC1101.4 (P0_3), TP1105.1; also elsewhere on the board
/Project Architecture/Lepton/~Lepton-Reset: IC1101.15 (P1_5), TP1106.1; also elsewhere on the board
/Project Architecture/MCU/~Expander-Int: IC1101.22 (~INT), R1102.1; also elsewhere on the board
/Project Architecture/Peripherals/Camera-PWR: IC1101.17 (P1_7), TP1103.1; also elsewhere on the board
/Project Architecture/Peripherals/LED-Flash_{1}: IC1104.2 (LED1), Q1101.1 (G), R1103.2, TP1112.1
/Project Architecture/Peripherals/LED-Flash_{2}: IC1104.1 (LED0), Q1102.1 (G), R1106.2, TP1113.1
/Project Architecture/Peripherals/~RTC-INT: IC1101.5 (P0_4), IC1105.3 (~INT), R1114.1, TP1108.1
/Project Architecture/Peripherals/~Range-INT: IC1101.8 (P0_7), IC1106.7 (GPIO1), R1113.1, TP1110.1
/Project Architecture/Peripherals/~SD-CD: IC1101.14 (P1_4), TP1107.1; also elsewhere on the board
/Project Architecture/Peripherals/~Temp-INT: IC1101.7 (P0_6), IC1102.3 (ALERT), R1105.1, TP1111.1
GND: C1101.2, C1102.2, C1103.2, C1104.2, C1105.2, C1106.2, C1107.2, IC1101.9 (V_{SS}), IC1101.18 (ADDR), IC1101.25 (EP), IC1102.2 (GND), IC1102.4 (ADD0), IC1103.1 (GND), IC1104.5 (GND), IC1105.2 (CLKOE), IC1105.4 (GND), IC1106.2 (AVSSVCSEL), IC1106.3 (GND), IC1106.4 (GND), IC1106.6 (GND), IC1106.12 (GND), Q1101.2 (S), Q1102.2 (S), R1103.1, R1106.1; also elsewhere on the board
unnamed: D1101.2 (A), R1104.1
unnamed: D1101.1 (K), Q1101.3 (D)
unnamed: D1102.2 (A), R1107.1
unnamed: D1102.1 (K), Q1102.3 (D)
unnamed: C1101.1, IC1101.24 (~RESET), R1101.1
unnamed: IC1103.7 (VCC_{2}), IC1103.8 (EN), R1110.2
unnamed: IC1103.6 (SCL_{2}), IC1105.8 (SCL), R1111.1
unnamed: IC1103.5 (SDA_{2}), IC1105.1 (SDA), R1112.1
unnamed: IC1106.5 (XSHUT), R1115.2

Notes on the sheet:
ToF Sensor
LED-Flash
PWM-Controller
Test points
Port Expander
Temperatur sensor
[${#}] ${TITLE}
RTC and Level shifting (RTC IO <> System Voltage)

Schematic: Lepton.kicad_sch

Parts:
C1001, C1002, C1004: 100n; C_0603_1608Metric; mouser# 581-06031C104MAT2A
C1003: 10n; C_0603_1608Metric; mouser# 581-06035A103KAT2A
IC1001, IC1003: TXB0104RUT; Texas_R-PUQFN-N12; mouser# 595-TXB0104RUTR
IC1002: PCA9306JK; XSON-8_0.65x0.17mm_P0.35mm; mouser# 771-PCA9306JKZ
R1001, R1003: 100k; R_0603_1608Metric; mouser# 652-CR0603-JW-104ELF
R1002: 0R; R_0603_1608Metric; mouser# 652-CR1206-J/-000ELF
R1004, R1005: 3k3; R_0603_1608Metric; mouser# 603-RC0603FR-073K3L
R1006: 200k; R_0603_1608Metric; mouser# 603-RC0603FR-07200KL
TP1001: TestPoint_Pad_1.0x1.0mm
X1001: LEPTON; 105028-1001; mouser# 538-105028-1001
Y1001: 25 MHz; Oscillator_SMD_Abracon_ASDMB-4Pin_2.5x2.0mm; mouser# 815-ASDDV2500MHZLCT3

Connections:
+3V3: IC1001.1 (VCCA), IC1001.12 (OE), IC1003.1 (VCCA), IC1003.12 (OE), R1006.1; also elsewhere on the board
/Project Architecture/Battery/I2C-SCL: IC1002.6 (SCL_{2}); also elsewhere on the board
/Project Architecture/Battery/I2C-SDA: IC1002.5 (SDA_{2}); also elsewhere on the board
/Project Architecture/Lepton/Lepton-MISO: IC1003.4 (A3); also elsewhere on the board
/Project Architecture/Lepton/Lepton-MISO_{LV}: IC1003.8 (B3), X1001.12
/Project Architecture/Lepton/Lepton-SCLK: IC1003.3 (A2); also elsewhere on the board
/Project Architecture/Lepton/Lepton-SCLK_{LV}: IC1003.9 (B2), X1001.13
/Project Architecture/Lepton/Lepton-VSync: IC1001.5 (A4); also elsewhere on the board
/Project Architecture/Lepton/Lepton-VSync_{LV}: IC1001.7 (B4), X1001.2
/Project Architecture/Lepton/SCL_{LV}: IC1002.3 (SCL_{1}), R1004.1, X1001.21
/Project Architecture/Lepton/SDA_{LV}: IC1002.4 (SDA_{1}), R1005.1, X1001.22
/Project Architecture/Lepton/~Lepton-CS: IC1003.2 (A1); also elsewhere on the board
/Project Architecture/Lepton/~Lepton-CS_{LV}: IC1003.10 (B1), X1001.14
/Project Architecture/Lepton/~Lepton-PWR: IC1001.3 (A2); also elsewhere on the board
/Project Architecture/Lepton/~Lepton-PWR_{LV}: IC1001.9 (B2), R1001.2, X1001.23
/Project Architecture/Lepton/~Lepton-Reset: IC1001.4 (A3); also elsewhere on the board
/Project Architecture/Lepton/~Lepton-Reset_{LV}: IC1001.8 (B3), R1003.2, X1001.24
GND: C1001.2, C1002.2, C1003.2, C1004.2, IC1001.6 (GND), IC1002.1 (GND), IC1003.6 (GND), R1002.2, X1001.1, X1001.6, X1001.8, X1001.9, X1001.10, X1001.15, X1001.18, X1001.20, X1001.25, X1001.27, X1001.30, Y1001.2 (GND); also elsewhere on the board
Lepton-1V2: C1002.1, X1001.7; also elsewhere on the board
Lepton-2V8: C1001.1, X1001.19; also elsewhere on the board
Lepton-3V0: C1003.1, C1004.1, IC1001.11 (VCCB), IC1002.2 (VCC_{1}), IC1003.11 (VCCB), R1001.1, R1003.1, R1004.2, R1005.2, X1001.16, Y1001.1 (Tri-State), Y1001.4 (VDD); also elsewhere on the board
unnamed: IC1002.7 (VCC_{2}), IC1002.8 (EN), R1006.2
unnamed: R1002.1, X1001.11
unnamed: TP1001.1, X1001.26, Y1001.3 (OUT)

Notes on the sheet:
Lepton 3.5 camera connector
DESIGN NOTE: MOSI is not used and should be grounded (see datasheet).
Level shifting (Lepton IO <> System Voltage)
[${#}] ${TITLE}

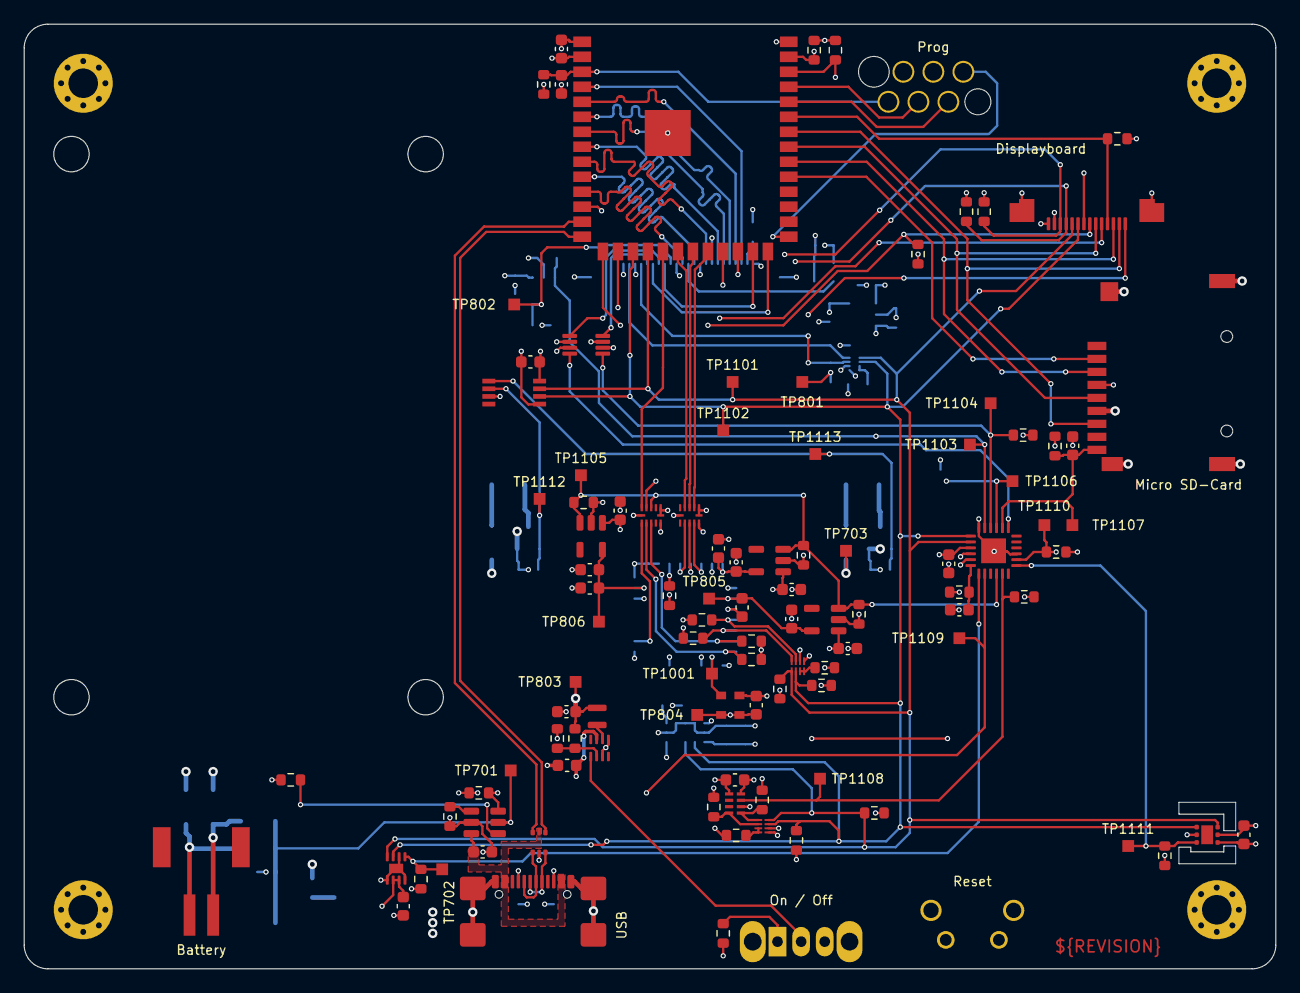
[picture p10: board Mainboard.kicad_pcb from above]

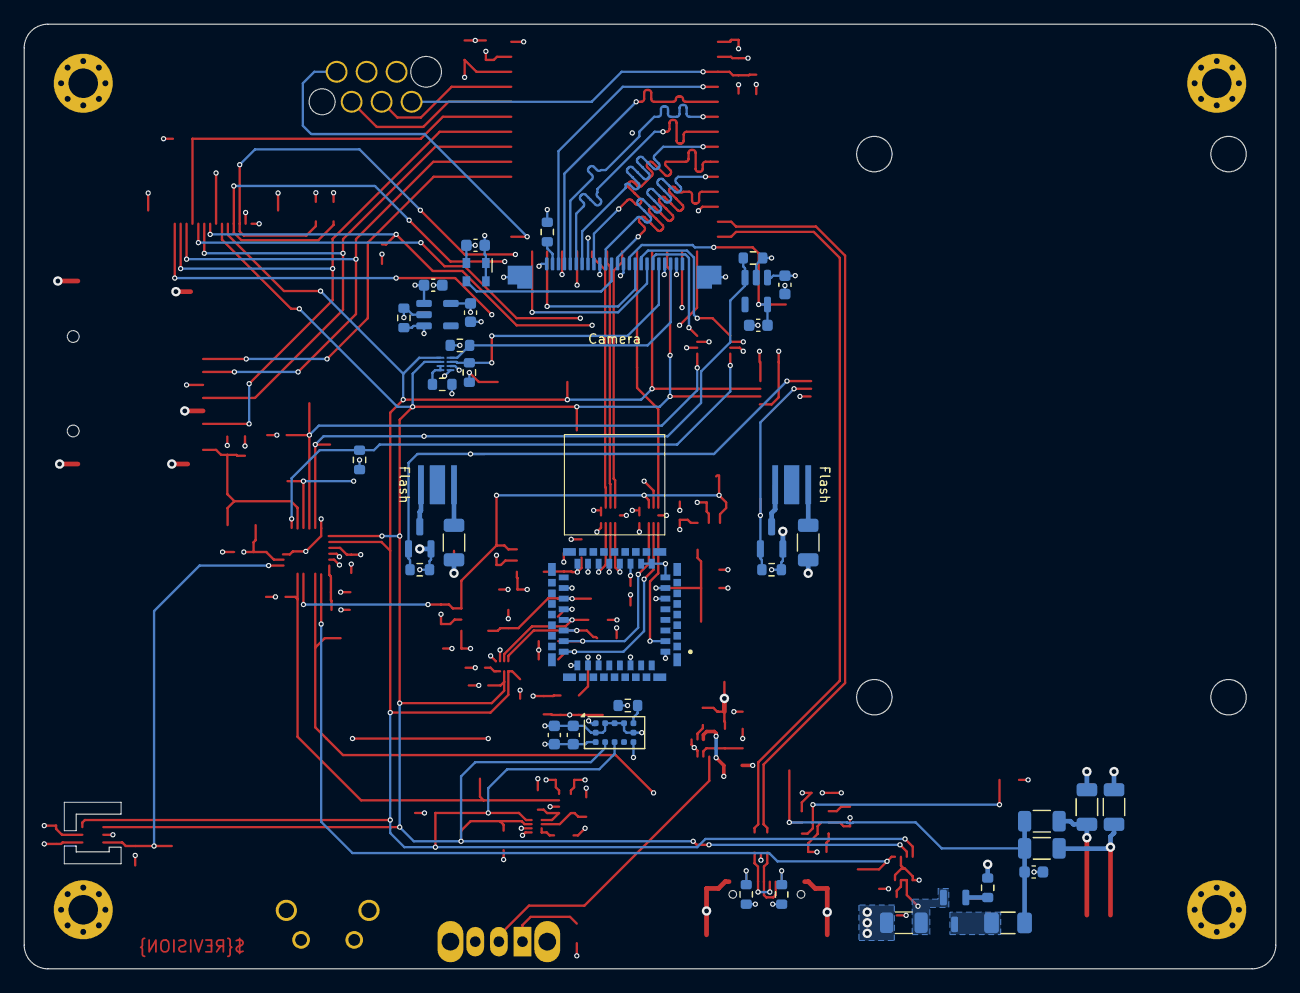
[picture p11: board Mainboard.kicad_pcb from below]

Board: 4 copper layers, 106.0 x 80.0 mm, 148 parts (41 on the bottom side), 100 nets.

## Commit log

2026-01-19 Initialize branch
    [Battery.kicad_sch, Block Diagram.kicad_sch, Camera.kicad_sch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]
2026-01-19 Continue routing, add flash LEDs for the RGB camera, add PWM controller for the Display Backlight and the flash LEDs, add Polyfuse for the battery
    [Battery.kicad_sch, Camera.kicad_sch, Display.kicad_sch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]
2026-01-19 Remove ADC for battery measurement and add a fuel gauge
    [Battery.kicad_sch, Camera.kicad_sch, Interface-Tree.kicad_sch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]
2026-01-19 New position for display connector
    [Display.kicad_sch, Lepton.kicad_sch, MCU.kicad_sch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]
2026-01-19 Replace temperature sensor and optimize the position, replace LiPo battery with a flat one
    [Battery.kicad_sch, Mainboard.kicad_pcb, Peripherals.kicad_sch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]
2026-01-19 Layout complete
    [Battery.kicad_sch, Block Diagram.kicad_sch, Camera.kicad_sch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]
2026-01-19 Add reset switch
    [MCU.kicad_sch, Mainboard.kicad_pcb]
2026-01-19 Release 1.0.0
    [Battery.kicad_sch, Mainboard.kicad_pcb, Peripherals.kicad_sch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]
2026-01-19 Push outputs from CI/CD (2026-01-19 19:04:05)
    [Mainboard-(L1-L4)_NPTH_drill_table.csv, Mainboard-(L1-L4)_drill_table.csv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]
2026-01-19 Update outputs (release)
    [Mainboard-(L1-L4)_NPTH_drill_table.csv, Mainboard-(L1-L4)_drill_table.csv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]
2026-01-21 Initialize development branch for version 1.0.1
    [Mainboard-(L1-L4)_NPTH_drill_table.csv, Mainboard-(L1-L4)_drill_table.csv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]
2026-01-21 Task: Issue #7
    - Increase the width of the cutout for the temperature sensor
    - Add missing component informations
    - Fix wrong component informations
    Closes: #7
    [Battery.kicad_sch, Camera.kicad_sch, Lepton.kicad_sch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]
2026-01-21 Bug: Issue #8
    - Drill drawing is missing
    Closes: #8
    [Mainboard.kicad_pcb]
2026-01-21 Add feedback from PCBWay
    [Battery.kicad_sch, Mainboard.kicad_pcb, Peripherals.kicad_sch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]
2026-01-21 Release 1.0.1
    [Mainboard.kicad_pcb]
2026-01-21 Push outputs from CI/CD (2026-01-21 18:28:46)
    [Mainboard-(L1-L4)_NPTH_drill_table.csv, Mainboard-(L1-L4)_drill_table.csv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]
2026-02-24 Initialize development branch for version 1.0.2
    [Mainboard-(L1-L4)_NPTH_drill_table.csv, Mainboard-(L1-L4)_drill_table.csv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]
2026-02-24 Change PCB color to green / white
    [Mainboard.kicad_pcb]
2026-02-24 Adjust dimensions
    [Mainboard.kicad_pcb]
2026-02-24 Bug: Issue #11
    - Add missing name for net for TP701
    Closes: #11
    [Battery.kicad_sch, Mainboard.kicad_pcb]
2026-02-24 Feature: Issue #10
    - Replace SD card holder with MSD-4-A
    Closes: #10
    [Mainboard.kicad_pcb, SD.kicad_sch]
2026-02-24 Bug: Fixing several component issues
    Closes: #17
    Closes: #16
    Closes: #15
    Closes: #14
    Closes: #13
    Closes: #12
    [Camera.kicad_sch, Lepton.kicad_sch, MCU.kicad_sch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]
2026-02-24 Feature: Issue #21
    - Connect the TMP117 temperatur alert pin
    - Add CI/CD workflow to check for changelog updates on pull requests
    Closes #21
    [Mainboard.kicad_pcb, Peripherals.kicad_sch]
2026-02-24 Feature: Issue #18
    - Replace XPGDWT-BS-0000-00Q2E with XPGDWT-BS-0000-00P5E
    - Update CHANGELOG with previous commits
    Closes: #18
    [Mainboard.kicad_pcb, Peripherals.kicad_sch]
2026-02-24 Add VL53L1X ToF sensor
    [Interface-Tree.kicad_sch, Lepton.kicad_sch, MCU.kicad_sch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]
2026-02-24 Push outputs from CI/CD (2026-02-23 15:32:47)
    [Mainboard-(L1-L4)_NPTH_drill_table.csv, Mainboard-(L1-L4)_drill_table.csv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]
2026-02-24 Prepare release 1.0.2
    [Camera.kicad_sch, Mainboard-(L1-L4)_NPTH_drill_table.csv, Mainboard-(L1-L4)_drill_table.csv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]
2026-02-25 Fix wrong datasheet link for the battery connector
    [Battery.kicad_sch, Mainboard.kicad_pcb]
2026-04-15 Changed: Fix PCB revision
    Closes: #24
    [Mainboard.kicad_pcb]
2026-04-15 Changed: Fix different minor assembly ToDos
    [Battery.kicad_sch, Camera.kicad_sch, Display.kicad_sch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]
2026-04-15 Removed: Remove camera PWD signal from camera power supply enable
    - The camera PWD signal is now used as a separate signal
    - Solves incompatible signal levels for both enable pins
    - Fix DRC issues
    [Camera.kicad_sch, Mainboard.kicad_pcb, Peripherals.kicad_sch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]
2026-04-15 Added: Add optional GND connection for camera AF on pin 24
    - Some camera module require a GND connection on this pin
    - CHANGELOG fixes
    [Camera.kicad_sch, Mainboard.kicad_pcb]

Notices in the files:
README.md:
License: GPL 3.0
